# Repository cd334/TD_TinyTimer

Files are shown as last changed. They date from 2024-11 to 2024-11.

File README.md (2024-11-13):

# TD_TinyTimer
This is a hardware design for [Phobos Lap Timer](https://github.com/phobos-/PhobosLT)

-----------------------------------------------------------------------
Copyright @ Dániel Czigány 2024.

This source describes Open Hardware and is licensed under the CERN-OHL-P v2

You may redistribute and modify this documentation and make products using it under the terms of the CERN-OHL-P v2 (https:/cern.ch/cern-ohl).
This documentation is distributed WITHOUT ANY EXPRESS OR IMPLIED WARRANTY, INCLUDING OF MERCHANTABILITY, SATISFACTORY QUALITY AND FITNESS FOR A PARTICULAR PURPOSE. Please see the CERN-OHL-P v2 for applicable conditions

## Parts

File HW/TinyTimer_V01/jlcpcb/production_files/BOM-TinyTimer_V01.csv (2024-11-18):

Comment | Designator | Footprint | LCSC | Quantity
SI2307CDS-T1-GE3 | Q2 | SOT-23 | C141561 | 1
100n/0603 | C1,C10,C14,C15,C17,C20,C21,C23,C24,C26,C3,C5,C6,C7 | C_0603_1608Metric | C14663 | 14
TPS3808DBV | U6 | SOT-23-6 | C19653 | 1
AO3400A | Q4 | SOT-23 | C20917 | 1
0R/0603 | R1,R2,R25,R5,R6,R7,R8 | R_0603_1608Metric | C21189 | 7
1k/0603 | R15,R16,R18,R19,R20,R23,R26 | R_0603_1608Metric | C21190 | 7
27k/0603 | R33 | R_0603_1608Metric | C22967 | 1
4k7/0603 | R28,R29 | R_0603_1608Metric | C23162 | 2
5k1/0603 | R12,R13 | R_0603_1608Metric | C23186 | 2
BSS138 | Q3 | SOT-23 | C255592 | 1
100k/0603 | R21,R30,R31,R34 | R_0603_1608Metric | C25803 | 4
10k/0603 | R10,R11,R14,R17,R27,R3,R4,R9 | R_0603_1608Metric | C25804 | 8
200k/0603 | R24 | R_0603_1608Metric | C25811 | 1
WS2812B | D7 | LED_WS2812B_PLCC4_5.0x5.0mm_P3.2mm | C2843785 | 1
Reset | SW1,SW2,SW3 | SW_SPST_B3U-1000P | C2905189 | 3
USB_C_Receptacle_USB2.0 | J1 | USB_C_Receptacle_HRO_TYPE-C-31-M-12 | C2927300 | 1
1042P | BT1 | BAT_1042P | C2988620 | 1
LESD5D5.0CT1G | D1,D2,D3 | D_SOD-523 | C383211 | 3
2k/0603 | R22 | R_0603_1608Metric | C4190 | 1
TLV75733PDBV | U3 | SOT-23-5 | C485517 | 1
UMH3N | Q1 | SOT-363_SC-70-6 | C62892 | 1
TP4054 | U5 | TSOT-23-5 | C668215 | 1
ESP32-WROOM-32UE | U1 | ESP32-WROOM-32UE | C701344 | 1
Green | D5 | LED_0603_1608Metric | C84264 | 1
Yellow | D6 | LED_0603_1608Metric | C84265 | 1
Blue | D8 | LED_0603_1608Metric | C84266 | 1
CH340C | U2 | SOIC-16_3.9x9.9mm_P1.27mm | C84681 | 1
B5819W SL | D4 | D_SOD-123 | C8598 | 1
47u/10V/1206 | C2 | C_1206_3216Metric | C96123 | 1
10u/0603 | C11,C12,C13,C16,C18,C19,C22,C25,C27,C4 | C_0603_1608Metric | C96446 | 10

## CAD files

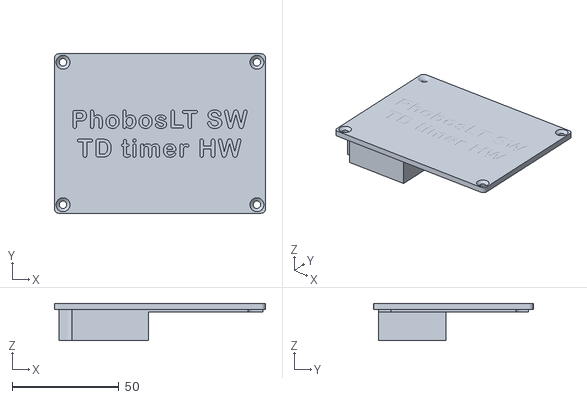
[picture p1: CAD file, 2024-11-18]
case/TD_Timer_top_V01.stl
98.9 x 74.8 x 17.5

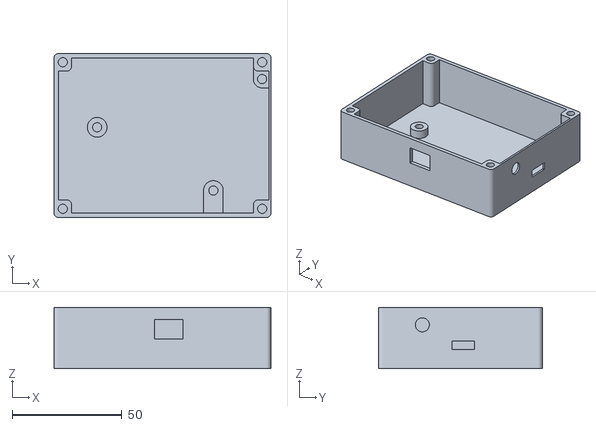
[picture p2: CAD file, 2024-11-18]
case/TD_Timer_bottom_V01.stl
98.9 x 74.8 x 28.0

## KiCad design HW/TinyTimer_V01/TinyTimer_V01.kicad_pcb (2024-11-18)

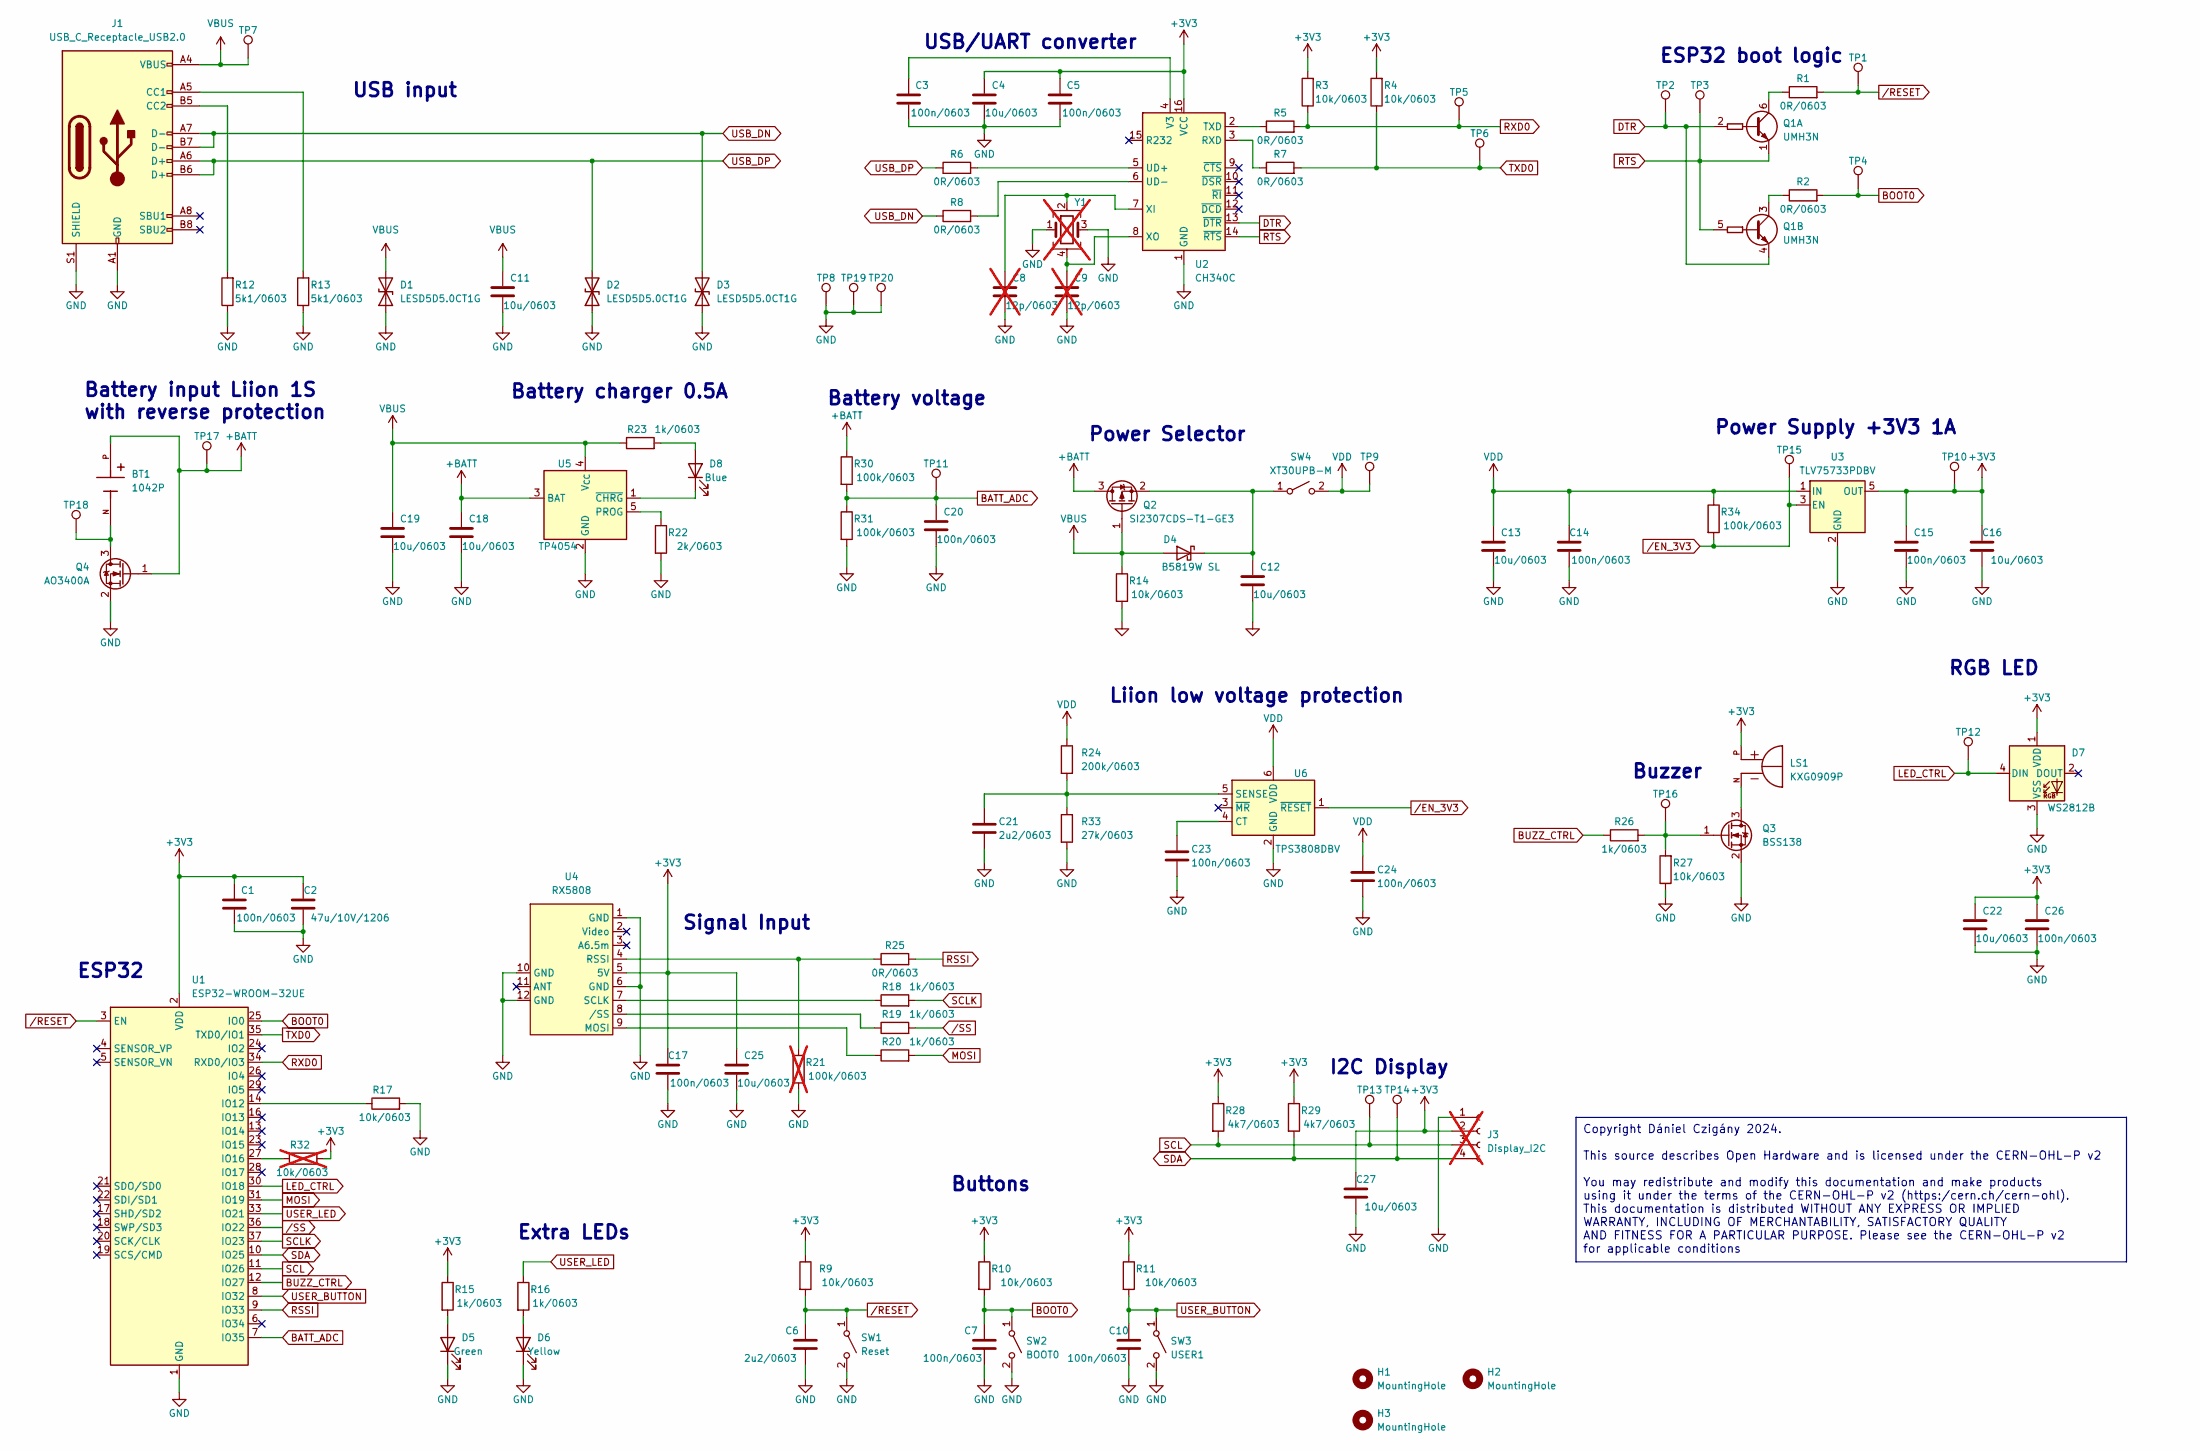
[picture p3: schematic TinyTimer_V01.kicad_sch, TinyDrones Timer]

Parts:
BT1: 1042P; BAT_1042P; PARTREV D; LCSC C2988620
C1, C3, C5, C7, C10, C14, C15, C17, C20, C23, C24, C26: 100n/0603; C_0603_1608Metric; LCSC C14663
C2: 47u/10V/1206; C_1206_3216Metric; JLCPCB C96123
C4, C11, C12, C13, C16, C18, C19, C22, C25, C27: 10u/0603; C_0603_1608Metric; LCSC C96446
C6, C21: 2u2/0603; C_0603_1608Metric; LCSC C14663
C8, C9: 12p/0603; C_0603_1608Metric; not fitted
D1, D2, D3: LESD5D5.0CT1G; D_SOD-523; LCSC C383211
D4: B5819W SL; D_SOD-123; LCSC C8598
D5: Green; LED_0603_1608Metric; LCSC C84264
D6: Yellow; LED_0603_1608Metric; LCSC C84265
D7: WS2812B; LED_WS2812B_PLCC4_5.0x5.0mm_P3.2mm; LCSC C2843785
D8: Blue; LED_0603_1608Metric; LCSC C84266
H1, H2, H3: MountingHole; MountingHole_3.5mm
J1: USB_C_Receptacle_USB2.0; USB_C_Receptacle_HRO_TYPE-C-31-M-12; LCSC C2927300
J3: Display_I2C; JST_XH_B4B-XH-A_1x04_P2.50mm_Vertical; not fitted
LS1: KXG0909P; XDCR_KXG0909P; PARTREV 1.1
Q1: UMH3N; SOT-363_SC-70-6; LCSC C62892
Q2: SI2307CDS-T1-GE3; SOT-23; LCSC C141561
Q3: BSS138; SOT-23; LCSC C255592
Q4: AO3400A; SOT-23; LCSC C20917
R1, R2, R5, R6, R7, R8, R25: 0R/0603; R_0603_1608Metric; LCSC C21189
R3, R4, R9, R10, R11, R14, R17, R27: 10k/0603; R_0603_1608Metric; LCSC C25804
R12, R13: 5k1/0603; R_0603_1608Metric; LCSC C23186
R15, R16, R18, R19, R20, R23, R26: 1k/0603; R_0603_1608Metric; LCSC C21190
R21: 100k/0603; R_0603_1608Metric; LCSC C25803; not fitted
R22: 2k/0603; R_0603_1608Metric; LCSC C4190
R24: 200k/0603; R_0603_1608Metric; LCSC C25811
R28, R29: 4k7/0603; R_0603_1608Metric; LCSC C23162
R30, R31, R34: 100k/0603; R_0603_1608Metric; LCSC C25803
R32: 10k/0603; R_0603_1608Metric; LCSC C25804; not fitted
R33: 27k/0603; R_0603_1608Metric; LCSC C22967
SW1: Reset; SW_SPST_B3U-1000P; LCSC C2905189
SW2: BOOT0; SW_SPST_B3U-1000P; LCSC C2905189
SW3: USER1; SW_SPST_B3U-1000P; LCSC C2905189
SW4: XT30UPB-M; PhoenixContact_MCV_1,5_2-G-3.81_1x02_P3.81mm_Vertical
TP1, TP2, TP3, TP4, TP5, TP6, TP7, TP8, TP9, TP10, TP11, TP12, TP13, TP14, TP15, TP16, TP17, TP18: TestPoint; TestPoint_Pad_D1.0mm
TP19, TP20: TestPoint; TestPoint_THTPad_D3.0mm_Drill1.5mm
U1: ESP32-WROOM-32UE; LCSC C701344
U2: CH340C; SOIC-16_3.9x9.9mm_P1.27mm; LCSC C84681
U3: TLV75733PDBV; SOT-23-5; LCSC C485517
U4: RX5808; RX5808_THT
U5: TP4054; TSOT-23-5; LCSC C668215
U6: TPS3808DBV; SOT-23-6; LCSC C19653
Y1: Crystal_GND24; Crystal_SMD_3225-4Pin_3.2x2.5mm; not fitted

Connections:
+3V3: C1.1, C2.1, C4.1, C5.1, C15.1, C16.1, C17.1, C22.1, C25.1, C26.1, C27.1, D7.1 (VDD), J3.2, LS1.P, R3.2, R4.2, R9.1, R10.1, R11.1, R15.1, R28.1, R29.1, R32.2, TP10.1, U1.2 (VDD), U2.16 (VCC), U3.5 (OUT), U4.5 (5V)
+BATT: BT1.P, C18.1, Q2.3 (D), Q4.1 (G), R30.1, TP17.1, U5.3 (BAT)
BATT_ADC: C20.1, R30.2, R31.1, TP11.1, U1.7 (IO35)
BOOT0: C7.1, R2.2, R10.2, SW2.1 (A), TP4.1, U1.25 (IO0)
BUZZ_CTRL: R26.1, U1.12 (IO27)
DTR: Q1.2 (B1), Q1.4 (E2), TP2.1, U2.13 (~DTR)
GND: C1.2, C2.2, C3.2, C4.2, C5.2, C6.2, C7.2, C8.2, C9.2, C10.2, C11.2, C12.2, C13.2, C14.2, C15.2, C16.2, C17.2, C18.2, C19.2, C20.2, C21.2, C22.2, C23.2, C24.2, C25.2, C26.2, C27.2, D1.1 (A1), D2.1 (A1), D3.1 (A1), D5.1 (K), D6.1 (K), D7.3 (VSS), J1.A1 (GND), J1.A12 (GND), J1.B1 (GND), J1.B12 (GND), J1.S1 (SHIELD), J3.1, Q3.2 (S), Q4.2 (S), R12.1, R13.1, R14.2, R17.2, R21.2, R22.2, R27.1, R31.2, R33.2, SW1.2 (B), SW2.2 (B), SW3.2 (B), TP8.1, TP19.1, TP20.1, U1.1 (GND), U1.15 (GND), U1.38 (GND), U1.39 (GND), U2.1 (GND), U3.2 (GND), U4.1 (GND), U4.6 (GND), U4.10 (GND), U4.12 (GND), U5.2 (GND), U6.2 (GND), Y1.1, Y1.3
LED_CTRL: D7.4 (DIN), TP12.1, U1.30 (IO18)
MOSI: R20.2, U1.31 (IO19)
unnamed: C12.1, D4.1 (K), Q2.2 (S), SW4.1 (A)
unnamed: D5.2 (A), R15.2
unnamed: D6.2 (A), R16.2
unnamed: D8.2 (A), R23.2
unnamed: D8.1 (K), U5.1 (~CHRG)
unnamed: J1.A5 (CC1), R13.2
unnamed: J1.B5 (CC2), R12.2
unnamed: Q1.6 (C1), R1.1
unnamed: Q1.3 (C2), R2.1
unnamed: LS1.N, Q3.3 (D)
unnamed: Q3.1 (G), R26.2, R27.2, TP16.1
unnamed: BT1.N, Q4.3 (D), TP18.1
unnamed: R17.1, U1.14 (IO12)
unnamed: R32.1, U1.27 (IO16)
unnamed: R7.1, U2.3 (RXD)
unnamed: R5.1, U2.2 (TXD)
unnamed: R6.2, U2.5 (UD+)
unnamed: R8.2, U2.6 (UD-)
unnamed: C3.1, U2.4 (V3)
unnamed: C8.1, U2.7 (XI), Y1.2
unnamed: C9.1, U2.8 (XO), Y1.4
unnamed: R20.1, U4.9 (MOSI)
unnamed: R21.1, R25.1, U4.4 (RSSI)
unnamed: R18.1, U4.7 (SCLK)
unnamed: R19.1, U4.8 (/SS)
unnamed: R22.1, U5.5 (PROG)
unnamed: C23.1, U6.4 (CT)
unnamed: C21.1, R24.2, R33.1, U6.5 (SENSE)
RSSI: R25.2, U1.9 (IO33)
RTS: Q1.1 (E1), Q1.5 (B2), TP3.1, U2.14 (~RTS)
RXD0: R3.1, R5.2, TP5.1, U1.34 (RXD0/IO3)
SCL: J3.3, R28.2, TP13.1, U1.11 (IO26)
SCLK: R18.2, U1.37 (IO23)
SDA: J3.4, R29.2, TP14.1, U1.10 (IO25)
TXD0: R4.1, R7.2, TP6.1, U1.35 (TXD0/IO1)
USB_DN: D3.2 (A2), J1.A7 (D-), J1.B7 (D-), R8.1
USB_DP: D2.2 (A2), J1.A6 (D+), J1.B6 (D+), R6.1
USER_BUTTON: C10.1, R11.2, SW3.1 (A), U1.8 (IO32)
USER_LED: R16.1, U1.33 (IO21)
VBUS: C11.1, C19.1, D1.2 (A2), D4.2 (A), J1.A4 (VBUS), J1.A9 (VBUS), J1.B4 (VBUS), J1.B9 (VBUS), Q2.1 (G), R14.1, R23.1, TP7.1, U5.4 (V_{CC})
VDD: C13.1, C14.1, C24.1, R24.1, R34.1, SW4.2 (B), TP9.1, U3.1 (IN), U6.6 (VDD)
/EN_3V3: R34.2, TP15.1, U3.3 (EN), U6.1 (~RESET)
/RESET: C6.1, R1.2, R9.2, SW1.1 (A), TP1.1, U1.3 (EN)
/SS: R19.2, U1.36 (IO22)

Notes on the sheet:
Copyright Dániel Czigány 2024. This source describes Open Hardware and is licensed under the CERN-OHL-P v2 You may redistribute and modify this documentation and make products using it under the terms of the CERN-OHL-P v2 (https:/cern.ch/cern-ohl). This documentation is distributed WITHOUT ANY EXPR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
Power Supply +3V3 1A
ESP32
Battery input Liion 1S with reverse protection
USB input
Extra LEDs
Buttons
Battery charger 0.5A
Liion low voltage protection
I2C Display
RGB LED
Buzzer
Battery voltage
Signal Input
USB/UART converter
Power Selector
ESP32 boot logic

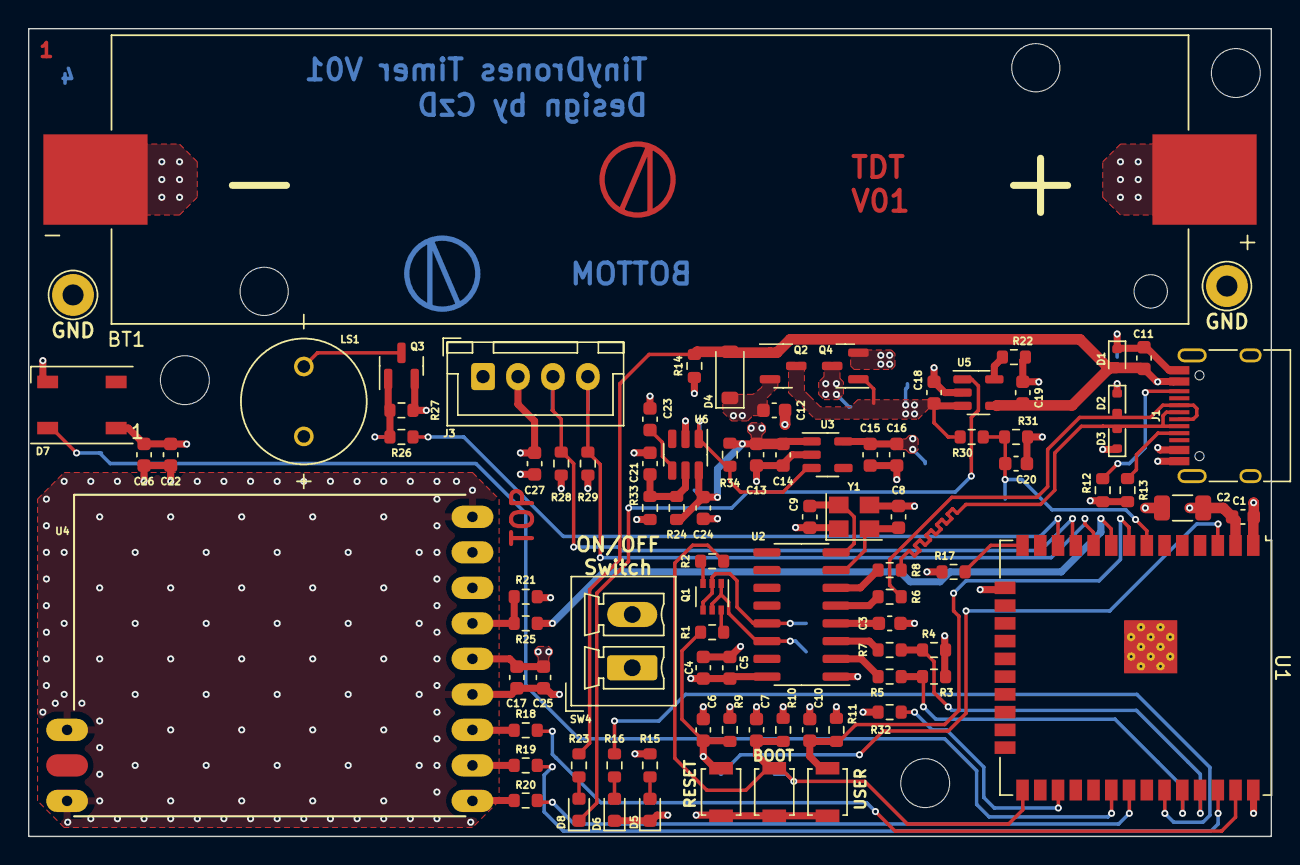
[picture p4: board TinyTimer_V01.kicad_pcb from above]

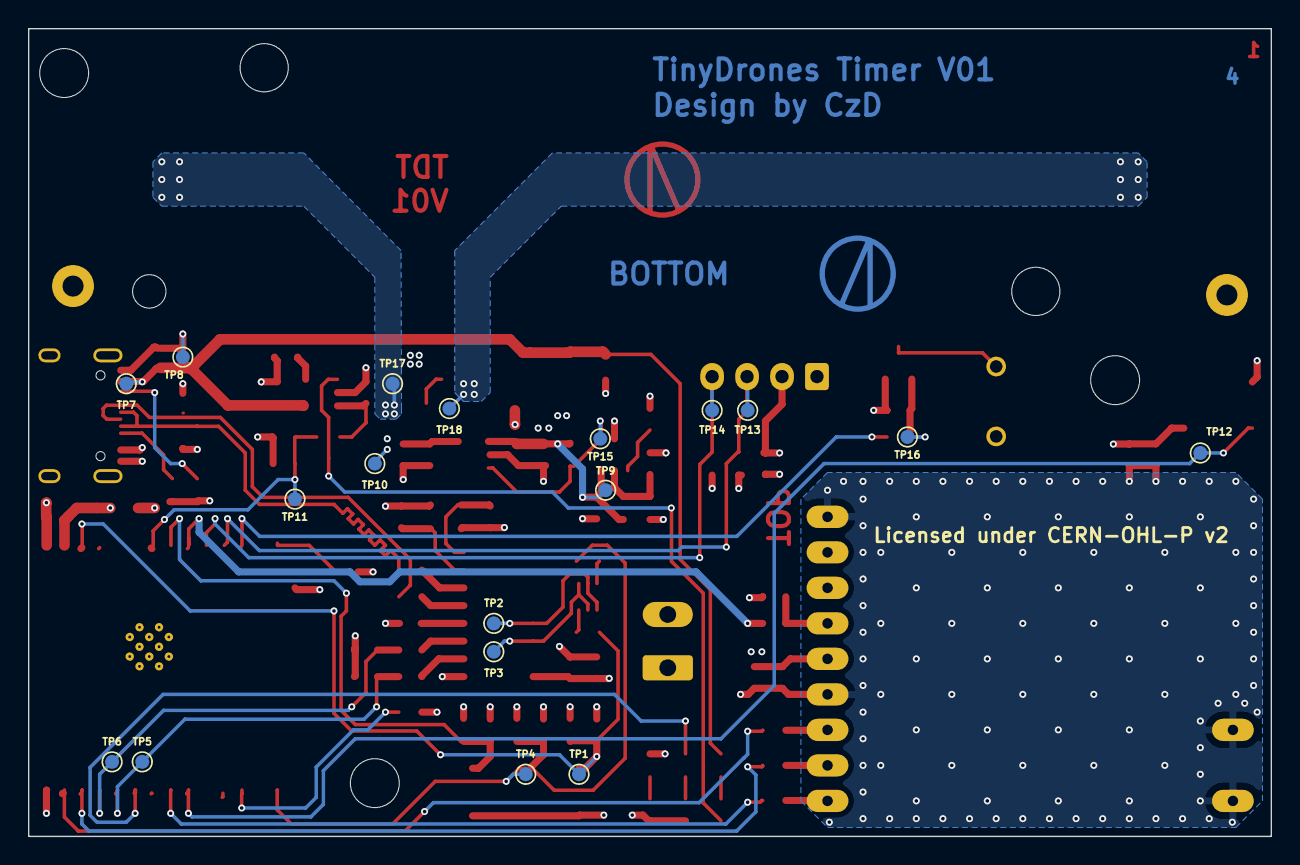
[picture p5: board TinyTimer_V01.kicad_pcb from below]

Board: 4 copper layers, 88.9 x 57.8 mm, 111 parts (18 on the bottom side), 53 nets.

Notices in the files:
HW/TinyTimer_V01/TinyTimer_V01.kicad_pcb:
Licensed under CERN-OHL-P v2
